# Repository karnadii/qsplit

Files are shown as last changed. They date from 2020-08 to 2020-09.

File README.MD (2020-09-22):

# QSPLIT

## Rev1
I want a split keyboard like quefrency but with encoder and oled just like satisfaction75
Splitted

## Rev2
Left using teensy++ 2.0 right using pro micro. I want a lot of feature but the pro micro firmware max size is limitting me from adding aditional feature. So I think of mixing different board. And it works. I almost never using the macro key on the left side and I want a dedicated encoder instead of changing layer encoder. And changing layout to make it easier for me to search for keycaps set. build log and the firmware coming soon.


## Hardware
| Component | qty | price | link | total Price |
|---|-----|---|---|---|
| Acrylic case and plate | 1 | Rp. 148.000 | https://www.tokopedia.com/acrylicsolo/custom-cutting-lasercut-acrylic-akrilik-3mm-murah-berkualitas | Rp. 148.000 |
| 120 Secondhand gateron brown | 1 | Rp. 330.000 | - | Rp. 330.000 |
| 30 Ws2812B LED RGB | 1 | Rp. 31.616  | https://shopee.co.id/product/59604415/4939222643 | Rp. 31.616  |
| Oled Lcd 128x32 0.91 inch I2C 12832 | 1 | Rp. 33.744  | https://shopee.co.id/product/170081862/5022580326 | Rp. 33.744  |
| 100PCS Self Adhesive Rubber Feet | 1 | Rp. 13.178  | https://shopee.co.id/product/141603612/4619155961 | Rp. 13.178  |
| Adapter Converter Type-C Female to Micro USB Male | 2 | Rp. 10.146  | https://shopee.co.id/product/167281669/3915263052 | Rp. 20.292  |
| Carbon keycap 104+21 laser engraved Oem Profile Pbt | 1 | Rp. 402.691 | https://shopee.co.id/product/274610761/7244255012 | Rp. 402.691 |
| 100pcs m2x25mm screw | 1 | Rp. 15.000  | - | Rp. 15.000  |
| 500pcs m2 nut | 1 | Rp. 20.000  | - | Rp. 20.000  |
| Magnet Neodymium Kotak 20x10x2mm | 10  | Rp. 2.200 | https://shopee.co.id/product/2654850/6002597796 | Rp. 20.200  |
| Pro Micro ATmega32U4 5V 16MHz | 2 | Rp. 52.141  | https://shopee.co.id/product/63841863/1693666309 | Rp. 104.282 |
| 4 Pole 3.5mm Stereo Headphone Male Plug Jack Audio | 2 | Rp. 8.778 | https://shopee.co.id/product/170081862/2774782378 | Rp. 17.556  |
| 4pcs Metal Electric Bass Guitar Volume Tone Control Knobs Dome | 1 | Rp. 32.718  | https://shopee.co.id/product/272832419/6939803069 | Rp. 32.718  |
| GENUINE CHERRY PLATE MOUNT STABILIZERS FULLSIZE | 1 | Rp. 210.000 | https://www.tokopedia.com/pixlup/genuine-cherry-plate-mount-stabilizers-stabilizer-fullsize | Rp. 210.000 |
| 1N4148 Fast Switching Diodes | 150 | Rp. 100 | https://shopee.co.id/product/52086903/5615237668 | Rp. 15.000  |
| Wire Stripper | 1 | Rp. 2.700 | https://shopee.co.id/product/52086903/5632591758 | Rp. 2.700 |
| Push button tact switch micro push button | 4 | Rp. 250 | https://shopee.co.id/product/52086903/4505572456 | Rp. 1.000 |
| 40meter 0.5mm copper wire | 1 | Rp. 32.500  | https://shopee.co.id/product/5773957/167997845 | Rp. 32.500  |
| Rotary encoder with switch EC11 | 1 | Rp. 4.617 | https://shopee.co.id/GHID-2PCS-Rotary-encoder-with-switch-EC11-Audio-digital-potentiometer-handle-20mm-i.170081862.2774808434 | Rp. 4.617 |
| 5pcs trrs female pcb | 1 | Rp. 19.339  | https://shopee.co.id/5pcs-Papan-Modul-Ekstensi-Jack-3.5mm-Untuk-Headset-Stereo-i.162080891.4234853478 | Rp. 19.339  |
|Total Price | | | |Rp. 1.474.433 ($100)|

This is my first time building custom handwired keyboard, even though someone else guide me to build this keeb. some mistakes were made, buying wrong part, buying unnecesery part to reach the minimum free shipping terms. buying to many part because the seller only sell in pack and so on. the cost not include the shipping cost, some part get free shipping some part don't. the cost not including the tool to build this keeb, like solder, soldering iron, caliper, multimeter and etc.

## Features
### Rotary encoder
the encoder have layers, you can change it to media layer, scrolling layer, backlit layer and brightness layer. To change encoder layer,simply press `fn1+encoder`. to change base layer like qwerty and so on use `fn2+encoder`.
#### Media layer
in media layer when you press the encoder it is a toogle button play pause `KC_MPLY`. when you turn the encoder clockwise and cc, it is acting as volume up and down (`KC_VOLU`,`KC_VOLD`). but when you turn the encoder while holding fn1 or fn2 it is acting as next and previous/fast forward and rewind button. my idea is awesome right? haha. explaining it in my non native lang is hard, just see my code.

```c
void handle_encoder_switch(void){
    if(ENCODER_MODE == media){
        tap_code(KC_MPLY);
    }
    ...
}
void handle_encoder_media(bool clockwise, bool fn1, bool fn2){
    if(clockwise){
        if(fn1){
            tap_code(KC_MNXT);
        }else if(fn2){
            tap_code(KC_MFFD);
        }else{
            tap_code(KC_VOLU);
        }
    }else {
        if(fn1){
            tap_code(KC_MPRV);
        }else if(fn2){
            tap_code(KC_MRWD);
        }else{
            tap_code(KC_VOLD);
        }
    }
}
```

#### Backlit layer
the idea is the same as media layer, when in this layer, the encoder button will act as ... just see my code
```c
void handle_encoder_switch(void){
    ...
    else if(ENCODER_MODE == backlit) {
        rgblight_step();
    }
    ...
}
void handle_encoder_backlit(bool clockwise, bool fn1, bool fn2){
    if(clockwise){
        if(fn1){
            rgblight_increase_hue();
        }else if(fn2){
            rgblight_increase_sat();
        }else{
            rgblight_increase_val();
        }
    }else {
        if(fn1){
            rgblight_decrease_hue();
        }else if(fn2){
            rgblight_decrease_sat();
        }else{
            rgblight_decrease_val();
        }
    }
}
```
#### Brightness layer
it is just brighness nothing else

### Scroll layer
```c
void handle_encoder_scroll(bool clockwise, bool fn1, bool fn2){
    if(clockwise){
        if(fn1){
            tap_code(KC_WH_R);
        }else if(fn2){
            tap_code(KC_WH_R);
        }else{
            tap_code(KC_WH_D);
        }
    }else {
        if(fn1){
            tap_code(KC_WH_L);
        }else if(fn2){
            tap_code(KC_WH_L);
        }else{
            tap_code(KC_WH_U);
        }
    }
}
```

### 128x32 Oled display
I want the same firmware as satisfaction75 the oled display is awesome, but I can't. So I use font image
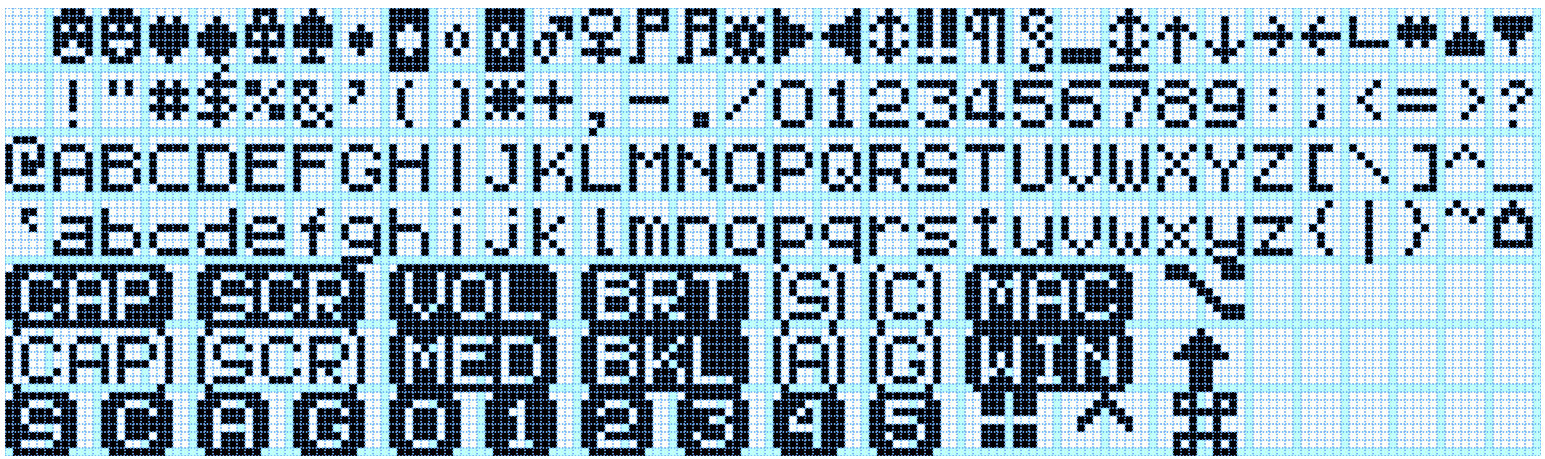
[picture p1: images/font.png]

edit font using https://helixfonteditor.netlify.app/

### 22 WS2812 RGB lightning (11 each halves)
nothing awesome about this

### Base layer
The base layer is just switching between qwerty mac and qwerty windows by pressing `fn2+encoder`, I can add another like dvorak colemak and etc but I don't want to learn them.

## Layout
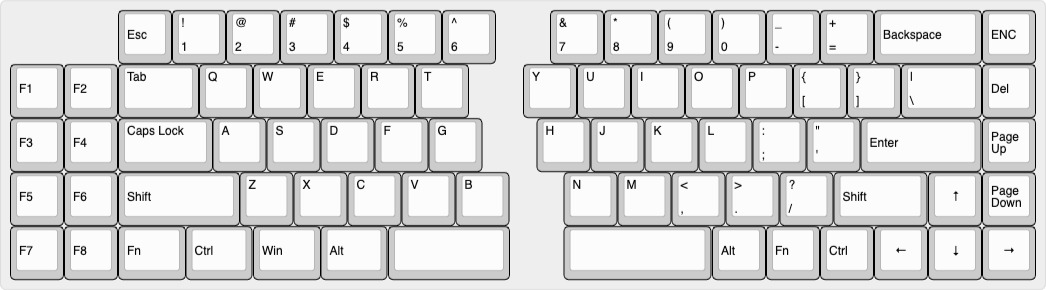
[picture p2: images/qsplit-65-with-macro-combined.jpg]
qsplit-65-with-macro-combined

Edit this layout in [http://www.keyboard-layout-editor.com](http://www.keyboard-layout-editor.com/##@_name=Qsplit%2065%20with%20macro%20combined&author=karnadii;&@_y:1&x:2.25&a:6;&=Esc&_a:4;&=!%0A1&=/@%0A2&=#%0A3&=$%0A4&=%25%0A5&=%5E%0A6&_x:1;&=/&%0A7&=*%0A8&=(%0A9&=)%0A0&=/_%0A-&=+%0A/=&_a:6&w:2;&=Backspace&=ENC;&@_x:0.25;&=F1&=F2&_a:4&w:1.5;&=Tab&=Q&=W&=E&=R&=T&_x:1;&=Y&=U&=I&=O&=P&=%7B%0A%5B&=%7D%0A%5D&_w:1.5;&=%7C%0A%5C&_a:6;&=Del;&@_x:0.25;&=F3&=F4&_a:4&w:1.75;&=Caps%20Lock&=A&=S&=D&=F&=G&_x:1;&=H&=J&=K&=L&=/:%0A/;&=%22%0A'&_a:6&w:2.25;&=Enter&=Page%20Up;&@_x:0.25;&=F5&=F6&_w:2.25;&=Shift&_a:4;&=Z&=X&=C&=V&=B&_x:1;&=N&=M&=%3C%0A,&=%3E%0A.&=?%0A//&_a:6&w:1.75;&=Shift&_a:7;&=%E2%86%91&_a:6;&=Page%20Down;&@_x:0.25;&=F7&=F8&_w:1.25;&=Fn&_w:1.25;&=Ctrl&_w:1.25;&=Win&_w:1.25;&=Alt&_a:7&w:2.25;&=&_x:1&w:2.75;&=&_a:6;&=Alt&=Fn&=Ctrl&_a:7;&=%E2%86%90&=%E2%86%93&=%E2%86%92)
## Finished Build
Splitted





more photos at [https://imgur.com/gallery/rXZYqem](https://imgur.com/gallery/rXZYqem)

## Wiring
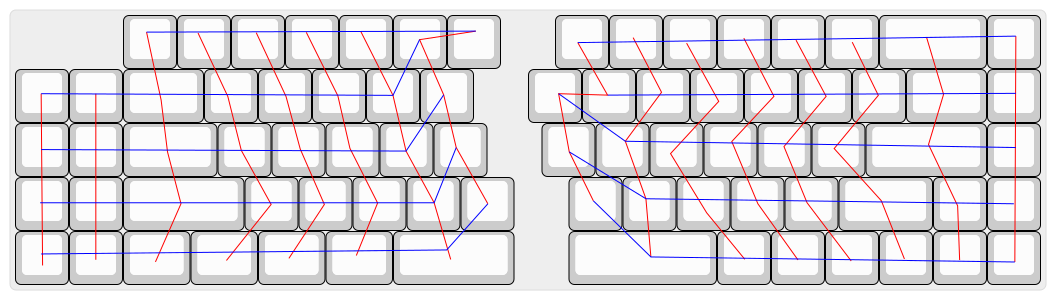
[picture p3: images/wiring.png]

communication protocol is serial using D3 pin, the LED Din pin use B5 pin, the right halve encoder connected to the i2c pin D1 and D0 so I have to disable the oled driver on the right halve to use encoder, and I can't use the Oled display if the right side is the master, always use left as master.

there is only 1 pin left, B5. I intend to use it for buzzer but the maximum size of pro micro firmware not allow me to add this feature :'(.

## Build Log
This is my first custom keyboard and it is a handwired. I am too excited to finish this keeb ASAP so I don't document my build. but here are some pictures of my build without timestamp.

### Acrylic case arrive
trying the switch on the double layer plate acrylic (1.5mm+3mm). It is fit and click without adding some glue. the doubleplate acrylic idea by @dayatz



### Starting build
at first it looks good




adding the pro micro, trrs, led and etc. Disgusting wiring.



this is suppose to be underglow


I trust my ability so no need to test it on breadboard.

## The end
I am learning so much by building this keyboard, at first it confusing, but once you understand how it works, you can build it faster.
I am not satisfied yet with this keyboard, I will upgrade the mcu and other part. just wait for rev2. forgive my typo and bad grammar,I try my best.

## Credits
Thanks for member of [Indonesian Mechanical Keyboard Group](https://discord.gg/t9yvV8y). Thank you so much [@herpiko](https://github.com/herpiko) for the inspiration and the thorough guide, [@dayatz](https://github.com/dayatz) for the double layer acrylic plate desain so I can reduce the cost. thanks [@sendz](https://github.com/sendz) for open sourcing his acrylic case design so I can learn to make my own version. Thanks for the qmk discord member for helping with some issue.

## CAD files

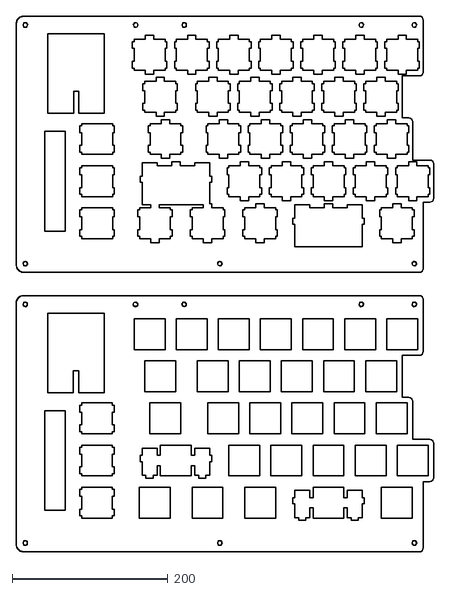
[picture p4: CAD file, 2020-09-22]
case/rev2/switch plate left.dxf
535.8 x 687.4

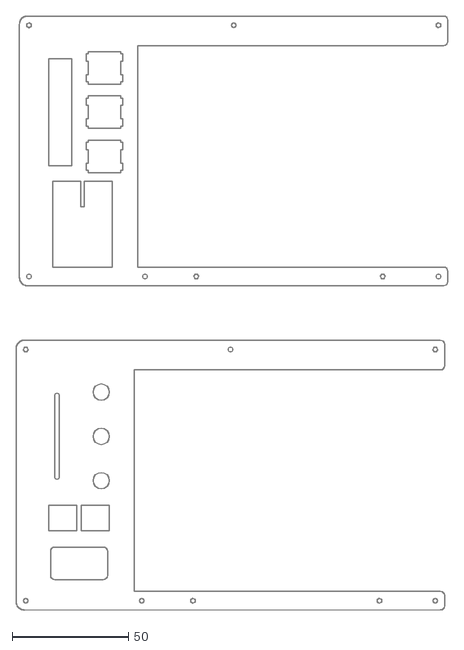
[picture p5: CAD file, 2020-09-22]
case/rev2/tes.dxf
185.6 x 255.5

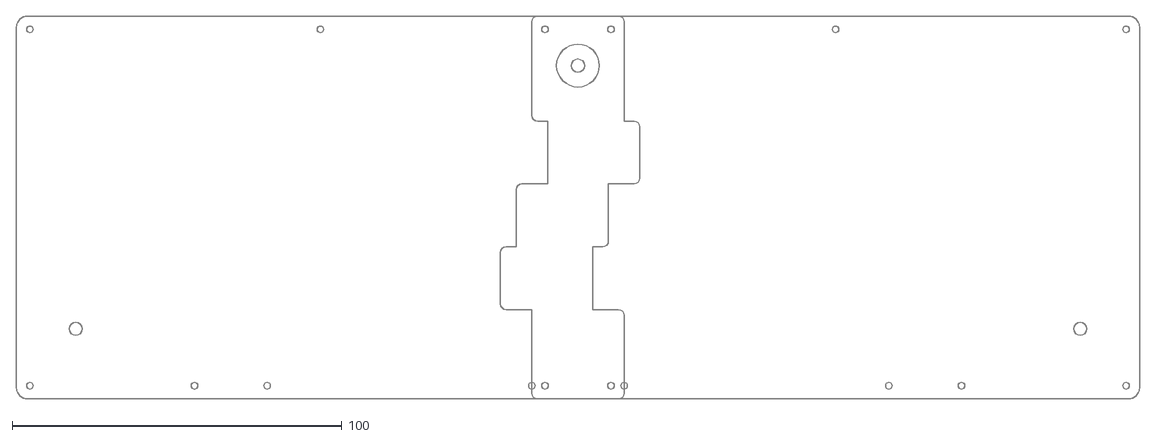
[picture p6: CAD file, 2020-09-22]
case/rev2/bottom plate.dxf
340.4 x 116.0

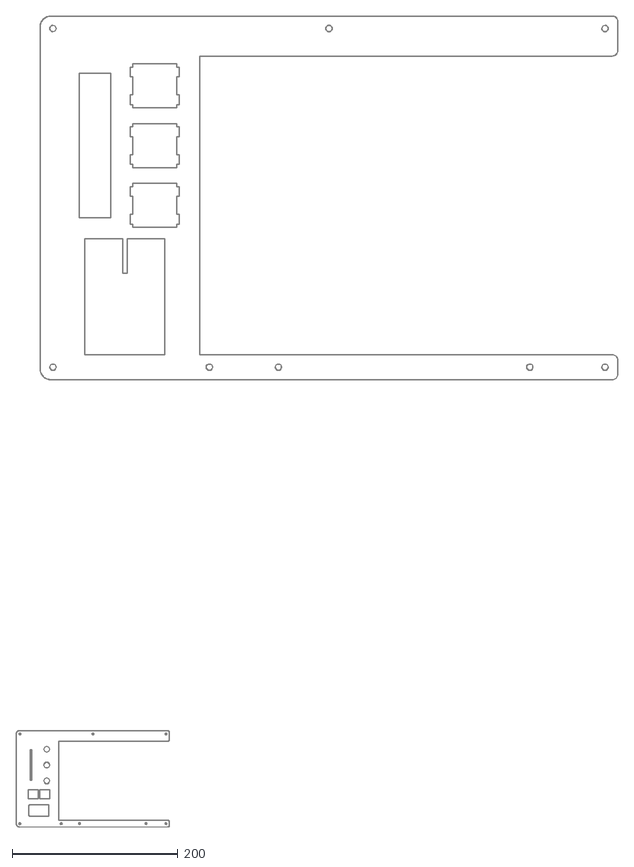
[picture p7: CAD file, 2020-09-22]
case/rev2/top layer left.dxf
724.8 x 977.7

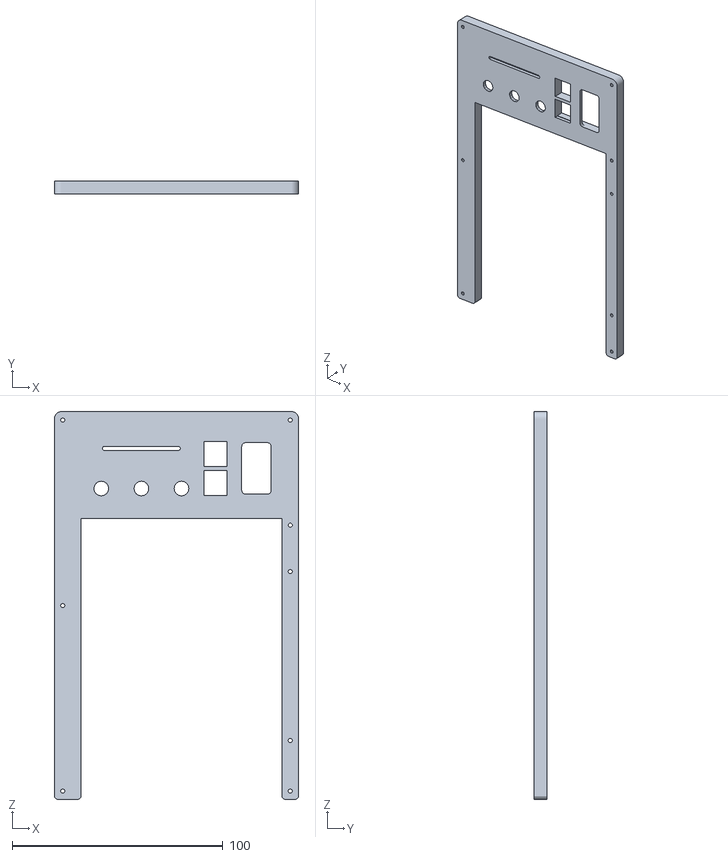
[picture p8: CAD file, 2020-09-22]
case/rev2/left top plate.stl
116.0 x 6.00 x 184.2

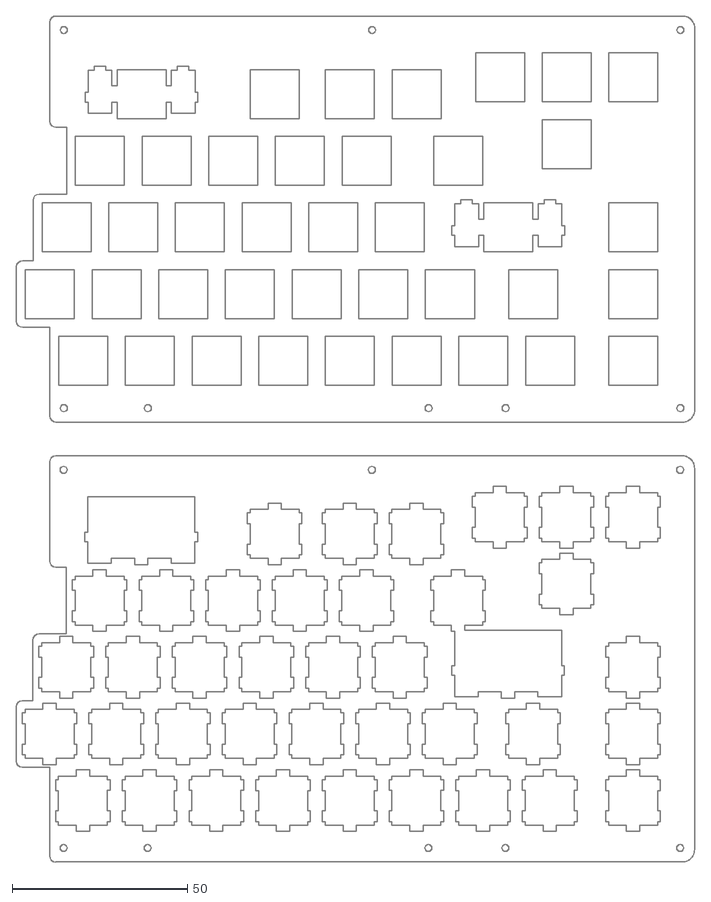
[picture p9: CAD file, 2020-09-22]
case/rev2/switch plate right.dxf
193.8 x 241.6

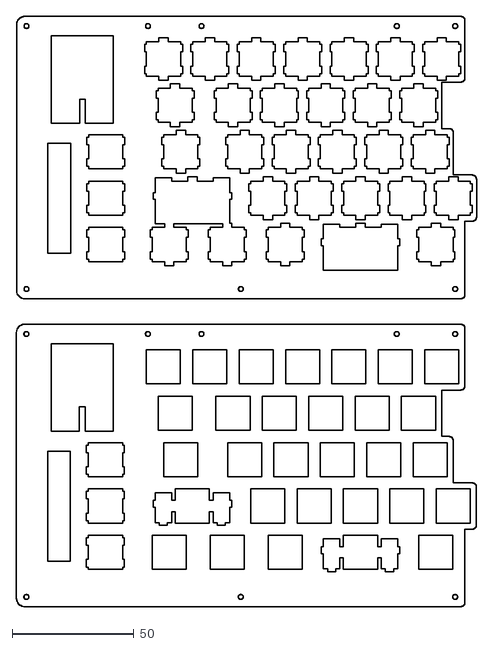
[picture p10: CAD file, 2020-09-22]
case/rev2/switch plate left rev.dxf
189.0 x 242.5

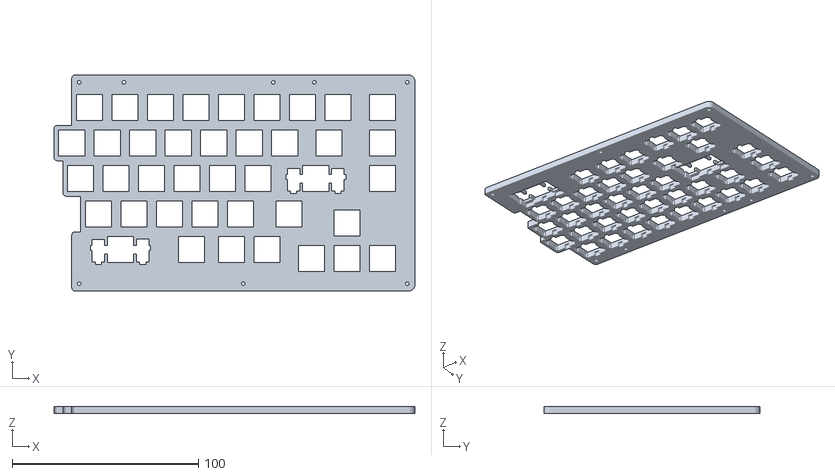
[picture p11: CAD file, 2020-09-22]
case/rev2/switch plate right revi.stl
193.7 x 116.0 x 4.00

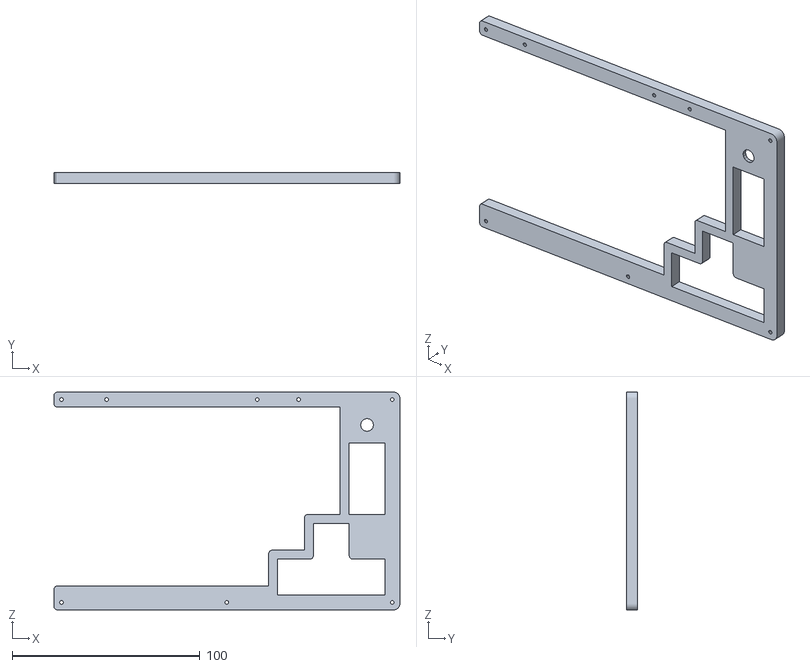
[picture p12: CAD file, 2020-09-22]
case/rev2/top layer right.stl
184.2 x 6.00 x 116.0

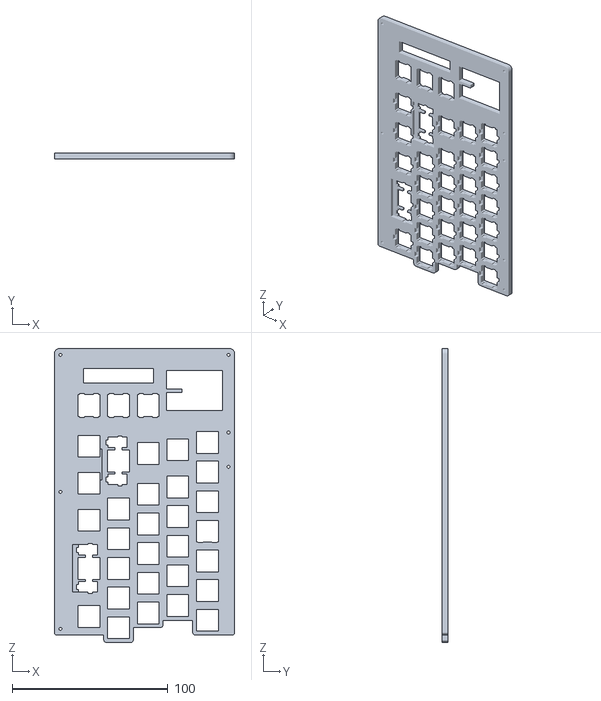
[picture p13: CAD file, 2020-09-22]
case/rev2/switch plate left rev2.stl
116.0 x 4.00 x 189.0

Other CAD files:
case/rev2/left top plate.dwg
case/rev2/switch plate left rev2.dwg
case/rev2/switch plate left rev2.dxf
case/rev2/switch plate right revi.dwg
case/rev2/switch plate right.dwg
case/rev2/top layer right.dwg
case/rev2/top layer right.dxf

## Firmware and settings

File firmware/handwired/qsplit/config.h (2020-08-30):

#ifndef CONFIG_H
#define CONFIG_H

#include "config_common.h"

/* USB Device descriptor parameter */
#define VENDOR_ID       0xFEED
#define PRODUCT_ID      0x6060
#define DEVICE_VER      0x0001
#define MANUFACTURER    karnadii
#define PRODUCT         qsplit65
#define DESCRIPTION     "handwired 65 keyboard + 8 macro with oled display and rotary encoder"

// #define MASTER_RIGHT // Comment this line for the left half firmware
#define MASTER_LEFT // Comment this line for the right half firmware

/* key matrix size */
#define MATRIX_ROWS 10
#define MATRIX_COLS 8

/* key matrix pins */
#define MATRIX_ROW_PINS { B1, F7, F6, F5, F4 }
#define MATRIX_COL_PINS { B3, B2, B6, E6, D7, C6, D4, D2 }
#define MATRIX_ROW_PINS_RIGHT { B1, F7, F6, F5, F4 }
#define MATRIX_COL_PINS_RIGHT { B3, B2, B6, E6, D7, C6, D4, D2 }
#define UNUSED_PINS
// #define USE_I2C
#define SOFT_SERIAL_PIN D3
/* COL2ROW or ROW2COL */
#define DIODE_DIRECTION COL2ROW

// Right encoder.
// I can not use only right encoder, I have to define left encoder as well
#define ENCODERS_PAD_A { D1 } // dummy encoder to passs error. there is no left encoder.
#define ENCODERS_PAD_B { D0 } // dummy encoder to passs error. there is no left encoder.
#define ENCODERS_PAD_A_RIGHT { D1 }
#define ENCODERS_PAD_B_RIGHT { D0 }
#define ENCODER_RESOLUTION 4

// #define RGBLIGHT_ANIMATIONS
#define RGBLIGHT_EFFECT_TWINKLE
#define RGBLIGHT_EFFECT_RAINBOW_MOOD
#define RGBLIGHT_EFFECT_ALTERNATING
#define RGBLIGHT_EFFECT_RAINBOW_SWIRL
#define RGBLED_NUM 22
#define RGBLED_SPLIT { 11, 11 }
#define RGB_DI_PIN B4

/* Set 0 if debouncing isn't needed */
#define DEBOUNCING_DELAY 0
#define OLED_FONT_H "keyboards/handwired/qsplit/keymaps/default/glcdfont.c"

#endif

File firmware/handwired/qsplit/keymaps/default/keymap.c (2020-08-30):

#include QMK_KEYBOARD_H
// #include <stdio.h>

// Each layer gets a name for readability, which is then used in the keymap matrix below.
// The underscores don't mean anything - you can have a layer called STUFF or any other name.
// Layer names don't all need to be of the same length, obviously, and you can also skip them
// entirely and just use numbers.
// #define _BASE 0
// #define _FN1 1
enum layer_names {
    _QWERTY_WIN,
    _QWERTY_MAC,
    _FN1,
    _FN2,
};

// char wpm_str[10];

enum custom_keycodes { QWERTY = SAFE_RANGE, LAYERMOD, ENCMOD, ENC_SWITCH };

enum enc_modes {  media, scroll, brightness, backlit };
enum operating_systems  { macos, windows };
uint8_t LAYER_MODE = _QWERTY_MAC;
uint8_t ENCODER_MODE   = media;
uint8_t OS_MODE   = macos;
bool is_capslock = false, is_scrolllock = false, is_lsft = false, is_lctl = false, is_lalt = false, is_lgui = false, is_fn1 = false, is_fn2 = false;

const uint16_t PROGMEM keymaps[][MATRIX_ROWS][MATRIX_COLS] = {

    [_QWERTY_WIN] = KEYMAP(
                      KC_GESC, KC_1, KC_2, KC_3, KC_4, KC_6,                   KC_7, KC_8, KC_9, KC_0, KC_MINS, KC_EQL, KC_BSPC, ENC_SWITCH,
        KC_F1, KC_F2, KC_TAB, KC_Q, KC_W, KC_E, KC_R, KC_5,                    KC_U, KC_I, KC_O, KC_P, KC_LBRC, KC_RBRC, KC_BSLS, KC_DEL,
        KC_F3, KC_F4, KC_CAPS, KC_A, KC_S, KC_D, KC_F, KC_T,                   KC_Y, KC_J, KC_K, KC_L, KC_SCLN, KC_QUOT, KC_ENT, KC_PGUP,
        KC_F5, KC_F6, KC_LSFT, KC_Z, KC_X, KC_C, KC_V, KC_G,                   KC_H, KC_M, KC_COMM, KC_DOT, KC_SLSH, KC_LSFT, KC_UP, KC_PGDN,
        KC_F7, KC_F8,  KC_LCTL, KC_LGUI, KC_LALT,MO(_FN2), KC_SPC, KC_B,       KC_N, KC_SPC, KC_LALT, MO(_FN1), KC_LCTL, KC_LEFT, KC_DOWN, KC_RGHT),

    [_QWERTY_MAC] = KEYMAP(
                      KC_GESC, KC_1, KC_2, KC_3, KC_4, KC_6,                   KC_7, KC_8, KC_9, KC_0, KC_MINS, KC_EQL, KC_BSPC, ENC_SWITCH,
        KC_F1, KC_F2, KC_TAB, KC_Q, KC_W, KC_E, KC_R, KC_5,                    KC_U, KC_I, KC_O, KC_P, KC_LBRC, KC_RBRC, KC_BSLS, KC_DEL,
        KC_F3, KC_F4, KC_CAPS, KC_A, KC_S, KC_D, KC_F, KC_T,                   KC_Y, KC_J, KC_K, KC_L, KC_SCLN, KC_QUOT, KC_ENT, KC_PGUP,
        KC_F5, KC_F6, KC_LSFT, KC_Z, KC_X, KC_C, KC_V, KC_G,                   KC_H, KC_M, KC_COMM, KC_DOT, KC_SLSH, KC_LSFT, KC_UP, KC_PGDN,
        KC_F7, KC_F8,  KC_LCTL,  KC_LALT, KC_LGUI, MO(_FN2), KC_SPC, KC_B,       KC_N, KC_SPC, KC_LGUI, MO(_FN1), KC_LCTL, KC_LEFT, KC_DOWN, KC_RGHT),

    // [_COLEMAK] = KEYMAP(
    //                 KC_GESC, KC_1, KC_2, KC_3, KC_4, KC_6,               KC_7, KC_8, KC_9, KC_0, KC_MINS, KC_EQL, KC_BSPC, ENC_SWITCH,
    //     KC_F1, KC_F2, KC_TAB, KC_Q, KC_W, KC_F, KC_P, KC_5,                    KC_L, KC_U, KC_Y, KC_SCLN, KC_LBRC, KC_RBRC, KC_BSLS, KC_END,
    //     KC_F3, KC_F4, KC_CAPS, KC_A, KC_R, KC_S, KC_T, KC_G,                   KC_J, KC_N, KC_E, KC_I, KC_O, KC_QUOT, KC_ENT, KC_PGUP,
    //     KC_F5, KC_F6, KC_LSFT, KC_Z, KC_X, KC_C, KC_V, KC_D,                   KC_H, KC_M, KC_COMM, KC_DOT, KC_SLSH, KC_LSFT, KC_UP, KC_PGDN,
    //     KC_F7, KC_F8,  KC_LCTL, KC_LALT, KC_LGUI, MO(_FN2), KC_SPC, KC_B,      KC_K, KC_SPC, KC_LGUI, MO(_FN2), KC_LCTL, KC_LEFT, KC_DOWN, KC_RGHT),

    [_FN1] = KEYMAP(
        KC_GRV, KC_F1, KC_F2, KC_F3, KC_F4, KC_F6,                                     KC_F7, KC_F8, KC_F9, KC_F10, KC_F11, KC_F12, KC_DEL, ENCMOD,
        _______, _______, _______, _______, _______, _______, _______, KC_F5,          _______, _______, _______, _______, _______, _______, _______, _______,
        _______, _______, _______, _______, _______, _______, _______, _______,        _______, _______, _______, _______, _______, _______, _______, _______,
        _______, _______, _______, _______, _______, _______, _______, _______,        _______, _______, _______, _______, _______, _______, _______, _______,
        _______, _______, _______, _______, _______, _______, _______, _______,        _______,_______, _______, _______, _______, _______, _______, _______),

    [_FN2] = KEYMAP(
        RGB_TOG, RGB_MODE_FORWARD, _______, RGB_MODE_SWIRL, RGB_MODE_RAINBOW, RGB_MODE_BREATHE,                          RGB_VAD, RGB_VAI, RGB_SAD, RGB_SAI, RGB_HUD, RGB_HUI, RGB_MOD, LAYERMOD,
        _______, _______, _______, _______, _______, _______, _______, _______,        _______, _______, _______, _______, _______, _______, _______, _______,
        _______, _______, _______, _______, _______, _______, _______, _______,        _______, _______, _______, _______, _______, _______, _______, _______,
        _______, _______, _______, _______, _______, _______, _______, _______,        _______, _______, _______, _______, _______, _______, _______, _______,
        _______, _______, _______, _______, _______, _______, _______, _______,        _______, _______, _______, _______, _______, _______, _______, _______),
};




void handle_encoder_media(bool clockwise, bool fn1, bool fn2){
    if(clockwise){
        if(fn1){
            tap_code(KC_MNXT);
        }else if(fn2){
            tap_code(KC_MFFD);
        }else{
            tap_code(KC_VOLU);
        }
    }else {
        if(fn1){
            tap_code(KC_MPRV);
        }else if(fn2){
            tap_code(KC_MRWD);
        }else{
            tap_code(KC_VOLD);
        }
    }
}

void handle_encoder_backlit(bool clockwise, bool fn1, bool fn2){
    if(clockwise){
        if(fn1){
            rgblight_increase_hue();
        }else if(fn2){
            rgblight_increase_sat();
        }else{
            rgblight_increase_val();
        }
    }else {
        if(fn1){
            rgblight_decrease_hue();
        }else if(fn2){
            rgblight_decrease_sat();
        }else{
            rgblight_decrease_val();
        }
    }
}

void handle_encoder_scroll(bool clockwise, bool fn1, bool fn2){
    if(clockwise){
        if(fn1){
            tap_code(KC_WH_R);
        }else if(fn2){
            tap_code(KC_WH_R);
        }else{
            tap_code(KC_WH_D);
        }
    }else {
        if(fn1){
            tap_code(KC_WH_L);
        }else if(fn2){
            tap_code(KC_WH_L);
        }else{
            tap_code(KC_WH_U);
        }
    }
}

void handle_encoder_brightnes(bool clockwise, bool fn1, bool fn2){
    if (clockwise) {
        tap_code(KC_BRIU);
    } else {
        tap_code(KC_BRID);
    }
}

void handle_encoder_layer_change(void){
    if(ENCODER_MODE == 3){
        ENCODER_MODE = 0;
    }else{
        ENCODER_MODE+=1;
    }
}

void handle_encoder(bool clockwise){
    bool is_fn1 = layer_state_is(_FN1);
    bool is_fn2 = layer_state_is(_FN2);

    if(ENCODER_MODE == media){
        handle_encoder_media(clockwise,is_fn1,is_fn2);
    }else if(ENCODER_MODE==scroll){
        handle_encoder_scroll(clockwise,is_fn1,is_fn2);
    }else if(ENCODER_MODE == backlit){
        handle_encoder_backlit(clockwise,is_fn1,is_fn2);
    }else{
        handle_encoder_brightnes(clockwise,is_fn1,is_fn2);
    }
}
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

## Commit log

2020-08-30 add sandwich case
2020-09-22 prepare for rev2 build
    [bottom plate.dxf, left top plate.dwg, left top plate.stl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]
